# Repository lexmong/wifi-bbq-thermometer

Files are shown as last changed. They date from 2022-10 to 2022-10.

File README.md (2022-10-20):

# wifi-bbq-thermometer

An ESP8266 based wifi bbq thermometer using angularjs and bootstrap.
<br>
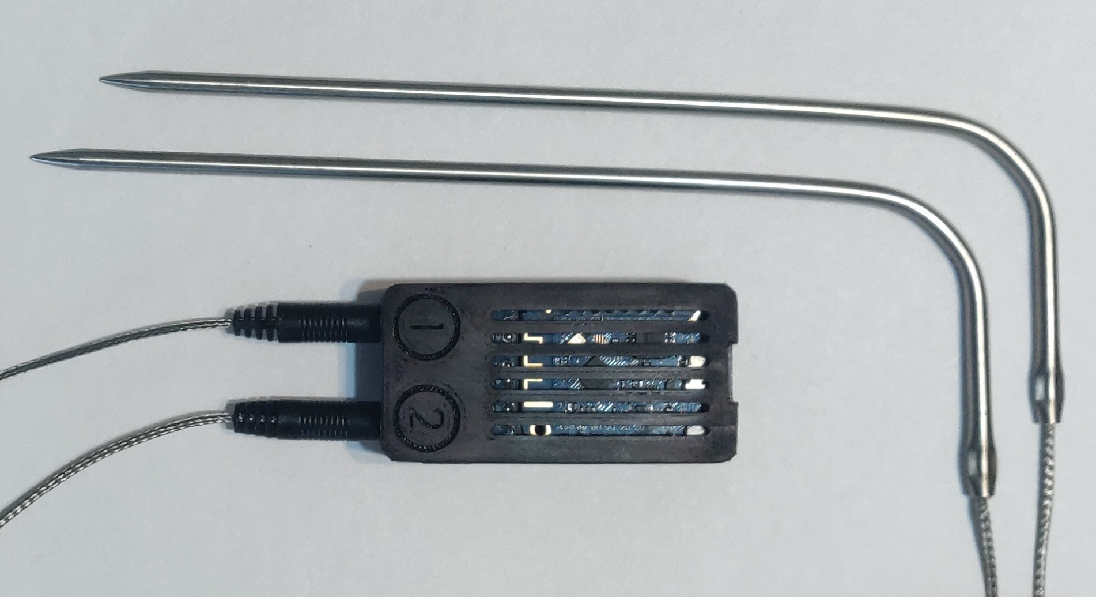
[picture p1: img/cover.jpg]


## Parts
|Qty|Part|Link|
|-|-|-|
|1|LOLIN D1 mini 3.1.0 |[Aliexpress](https://aliexpress.com/item/32831353752.html)|
|1|ADS1115 |[Aliexpress](https://aliexpress.com/item/32761481134.html)|
|2|2.5mm jack|[Aliexpress](https://aliexpress.com/item/32818269934.html)|
|2|Bbq probe (any should work)|[Aliexpress](https://aliexpress.com/item/1005001483369562.html)|
|6|4 pins female header|[Aliexpress](https://aliexpress.com/item/1005003610333849.html)|
|1|Male header (2x 8 pins + 1x 10 pins)|[Aliexpress](https://aliexpress.com/item/32623553746.html)|
|1|Perfboard (10x19 holes)||
|2|100kΩ resistor||

## Assembly
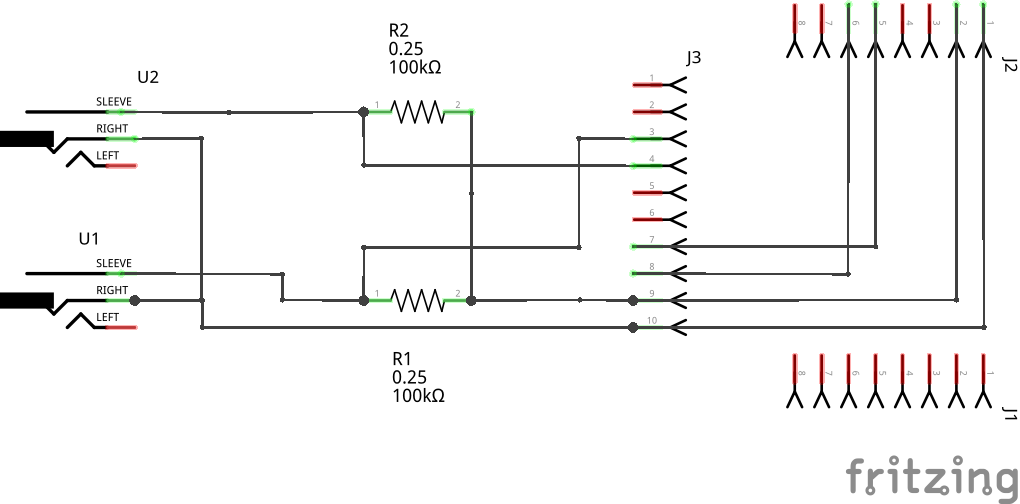
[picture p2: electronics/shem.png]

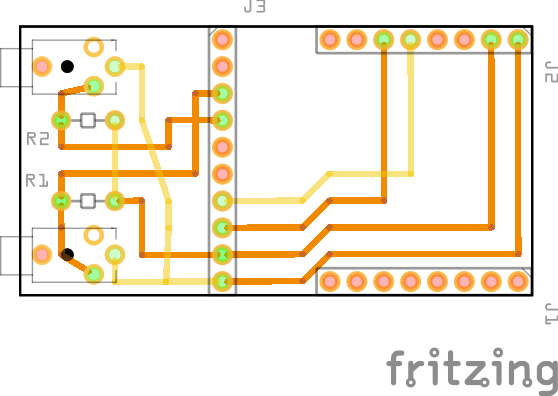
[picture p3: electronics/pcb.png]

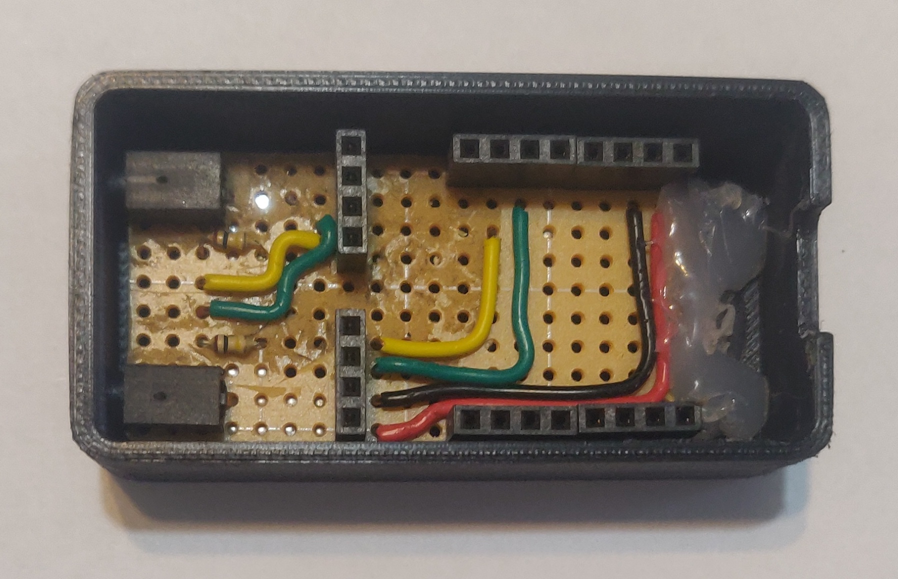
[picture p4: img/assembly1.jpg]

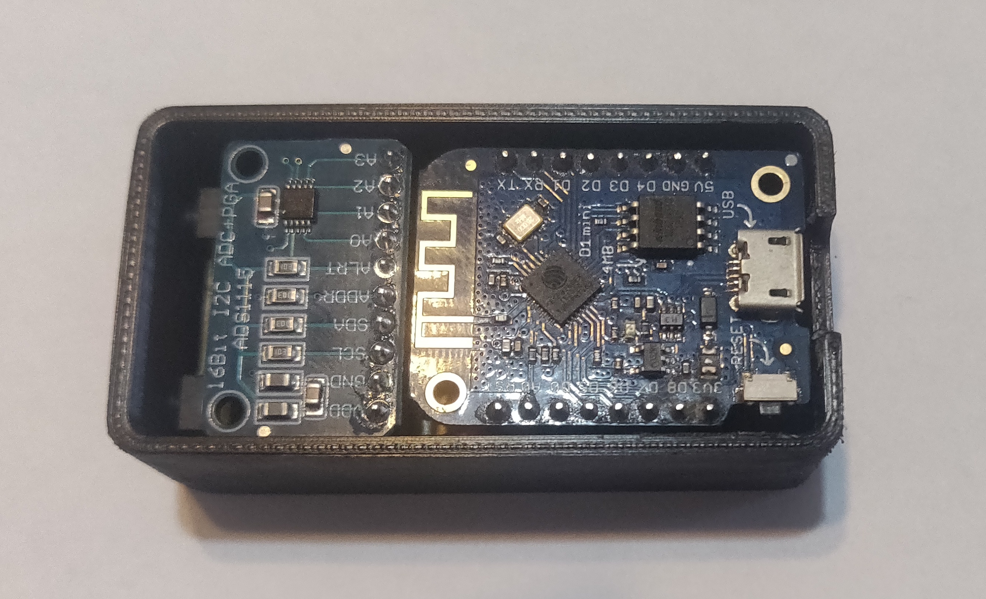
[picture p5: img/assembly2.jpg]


## Libraries
|Library|Link|
|-|-|
|ESP8266 Arduino Core|[Installation](https://arduino-esp8266.readthedocs.io/en/latest/installing.html)|
|Arduino ESP8266 filesystem uploader|[Installation](https://github.com/esp8266/arduino-esp8266fs-plugin)|
|ArduinoJson|[Installation](https://arduinojson.org/v6/doc/installation/)|
|Adafruit-ads1x15|[Installation](https://www.arduino.cc/reference/en/libraries/adafruit-ads1x15/)|

## Setup
1. Edit wifi_config_template.h
   - Set SSID, password, and hostname
   - Rename wifi_config_template.h to wifi_config.h
2. Upload sketch
3. Upload sketch data

## Probe calibration
Read the probe resistance at three different temperatures to calibrate. For best results, chose two temperatures close to the upper and lower bound of the operating range and one in the middle. Once submitted, the coefficients are calculated and saved to SPIFFS.



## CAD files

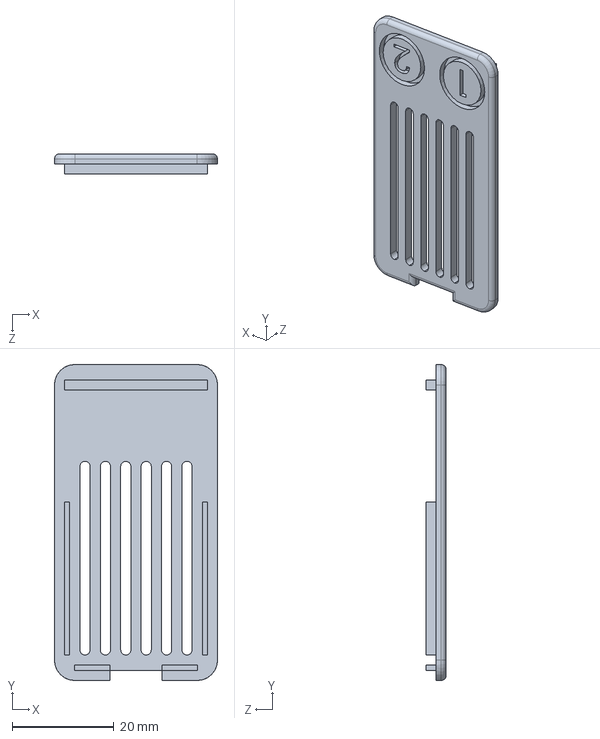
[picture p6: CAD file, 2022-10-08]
case/top.SLDPRT
32.0 x 62.0 x 4.00 mm

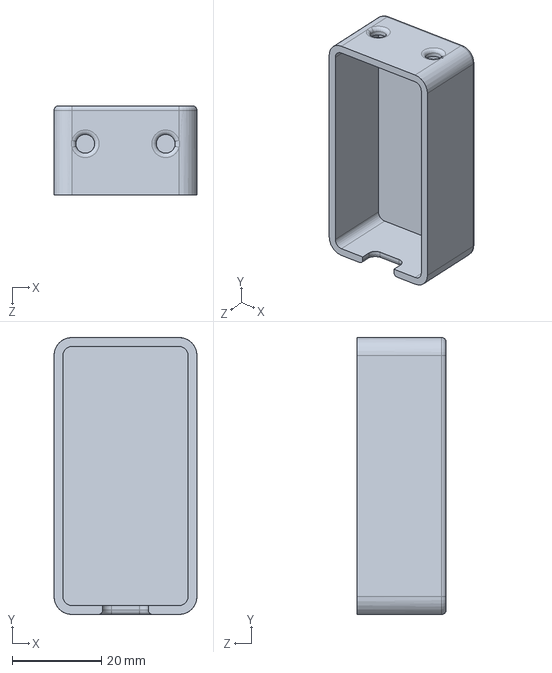
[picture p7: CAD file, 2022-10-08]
case/bottom.SLDPRT
32.0 x 62.0 x 20.0 mm

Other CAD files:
case/bottom.STL
case/top.STL

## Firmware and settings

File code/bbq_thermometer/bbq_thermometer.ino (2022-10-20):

#include <ArduinoJson.h>
#include <ESP8266WebServer.h>
#include <FS.h>
#include "wifi_config.h"
#include "utils.h"
#include "probe.h"
#include "network.h"

ESP8266WebServer server(80);
const int BUFFER_MAX = 1000;
char* PATH_COEFFICIENTS = "/coeffs.json";

void setup() {
  Serial.begin(115200);
  pinMode(LED_BUILTIN, OUTPUT);
  digitalWrite(LED_BUILTIN, LOW);
  
  initNetwork(WIFI_SSID,WIFI_PASSWORD,HOSTNAME);
  initAds();

  SPIFFS.begin();
  server.serveStatic("/", SPIFFS, "/index.html");
  server.serveStatic("/grill-outline.png", SPIFFS, "/grill-outline.png");
  server.serveStatic("/Poppins-Regular.ttf", SPIFFS, "/Poppins-Regular.ttf");
  server.serveStatic("/app.js", SPIFFS, "/app.js");
  server.serveStatic("/probes.html", SPIFFS, "/probes.html");
  server.serveStatic("/config.html", SPIFFS, "/config.html");
  server.serveStatic("/style.css", SPIFFS, "/style.css");

  if(loadCoefficients(PATH_COEFFICIENTS)){
    Serial.println("Coefficients loaded");
    for(int i =0; i< N_PROBES; i++){
      Serial.print("    probe ");
      Serial.println(i+1);
      for(int j=0;j<3;j++){
        Serial.print("        ");
        Serial.println(coeffs[i][j],10);
      }
    }
  }
  else Serial.println("Failed to load coefficents");

  server.onNotFound([](){
    server.send(404, "text/plain", "404: Not Found");
  });

  /**
   * Read temperature
   * GET args: unit ('c','f')
   */
  server.on("/readTemperature",[](){
    DynamicJsonDocument doc(BUFFER_MAX);
    char buf[BUFFER_MAX];
    double val;

    for(int i=0;i<N_PROBES;i++){
      val= getTemperature(getResistance(i),coeffs[i]);
      if(server.arg("unit") == "c") val = ktoc(val);
      else if(server.arg("unit") == "f") val = ktof(val);
      doc[i] = val;
    }
    
    serializeJson(doc, buf);
    server.send(200, "text/json", buf);
  });

  /**
   * Read resistance
   * GET args: probe (probe id 1 indexed)
   */
  server.on("/readResistance",[](){
    DynamicJsonDocument doc(BUFFER_MAX);
    char buf[BUFFER_MAX];
    int probe = server.arg("probe").toInt()-1;
    
    if(probe > -1 && probe < N_PROBES){
      doc[0] = getResistance(probe);
    }
    
    serializeJson(doc, buf);
    server.send(200, "text/json", buf);
  });

  /**
   * Calculates and returns coefficients 
   * GET args: 
   * points: JSON [{'temperature'=>t,'resistance'=>},{'temperature'=>t,'resistance'=>},...] 
   * probe: (probe id 1 indexed)
   * unit: c,f
   */
  server.on("/saveCoeffs",[](){
    DynamicJsonDocument doc(BUFFER_MAX);
    char buf[BUFFER_MAX];
    int probe;

    deserializeJson(doc,server.arg("points"));
    probe = server.arg("probe").toInt()-1;

    //fahrenheit
    if(server.arg("unit").charAt(0) == 102){
      doc[0]["temperature"] = ftoc(doc[0]["temperature"].as<double>());
      doc[1]["temperature"] = ftoc(doc[1]["temperature"].as<double>());
      doc[2]["temperature"] = ftoc(doc[2]["temperature"].as<double>());
    }

    
    getCoefficients(
      ctok(doc[0]["temperature"].as<double>()),
      ctok(doc[1]["temperature"].as<double>()),
      ctok(doc[2]["temperature"].as<double>()),
      doc[0]["resistance"].as<double>(),
      doc[1]["resistance"].as<double>(),
      doc[2]["resistance"].as<double>(),
      coeffs[probe]
    );

    doc.clear();

    doc["a"] = coeffs[probe][0];
    doc["b"] = coeffs[probe][1];
    doc["c"] = coeffs[probe][2];

    saveCoefficients(PATH_COEFFICIENTS);

    serializeJson(doc, buf);

    server.send(200, "text/json", buf);
  });

  server.begin();
  Serial.println("HTTP server started");
  digitalWrite(LED_BUILTIN, HIGH);
}

void loop() {
  MDNS.update();
  server.handleClient();
}

/***
 * Load coefficients from JSON file
 */
bool loadCoefficients(char* path) {
  StaticJsonDocument<1024> doc;
  File f;
  
  f = SPIFFS.open(path, "r");
  if(!f)return false;

 
  if(deserializeJson(doc, f)){
    f.close();
    return false;
  }

  for(int i =0; i< N_PROBES; i++){
    coeffs[i][0] = doc[i]["a"].as<double>();
    coeffs[i][1] = doc[i]["b"].as<double>();
    coeffs[i][2] = doc[i]["c"].as<double>();
  }

  f.close();
  return true;
}

/**
 * Save coefficients to JSON file
 */

bool saveCoefficients(char* path) {
  DynamicJsonDocument doc(BUFFER_MAX);
  File f;
  
  f = SPIFFS.open(path, "w");
  if(!f)return false;

  for(int i =0;i<N_PROBES;i++){
    doc[i]["a"] = coeffs[i][0];
    doc[i]["b"] = coeffs[i][1];
    doc[i]["c"] = coeffs[i][2];
  }

  serializeJson(doc,f);
  f.close();
  return false;
}

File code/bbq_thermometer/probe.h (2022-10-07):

#include <math.h>
#include <Adafruit_ADS1X15.h>

const int N_PROBES = 2;

Adafruit_ADS1115 ads;
double vRef = 4.52;
double rRef = 100000;
double coeffs[N_PROBES][3];

void initAds(){
  if (!ads.begin()) {
    Serial.println("Failed to initialize ADS.");
    while(1);
  }
  ads.setDataRate(7); 
  Serial.println("ADS initialized");
}

/**
 * Read resistance from adc
 * pin: input on the adc
 */
double getResistance(int pin){
  int16_t adc = ads.readADC_SingleEnded(pin);
  double volts= ads.computeVolts(adc);
  return volts > 0? rRef * (vRef/volts) - rRef:-1;
}

/**
 * Get temperature from resistance and Steinhart–Hart coefficients
 * res: resistance in ohm
 * coeffs: coefficients double[3]
 */
double getTemperature(double res,double* coeffs){
  if(res<0) return -1;
  double temp = log(res);
  temp = 1 / (coeffs[0] + (coeffs[1] * temp) + (coeffs[2] * temp * temp * temp));

  return temp;
}

/**
 * Get coefficients of Steinhart–Hart from 3 points  
 * k1,k2,k3: temperature in Kelvin
 * r1,r2,r3: resistance in ohm
 * 
 * https://en.wikipedia.org/wiki/Steinhart%E2%80%93Hart_equation
 */ 
void getCoefficients(double k1,double k2,double k3,double r1,double r2,double r3,double* coeffs){
    if(r1 == 0 || r2 ==0 || r3 == 0) return;
    if (r1 == r2 || r1 == r3 || r2 == r3) return;
    
    double l1 = log(r1),l2 = log(r2),l3 = log(r3);
    if(l1+l2+l3 == 0) return;
    
    double y1 = 1/k1, y2 = 1/k2,y3 = 1/k3;
    double g2 = (y2-y1)/(l2-l1),g3 = (y3-y1)/(l3-l1);
    
    coeffs[2] = (g3-g2)/(l3-l2)*(1/(l1+l2+l3));
    coeffs[1] = g2-coeffs[2] *(l1*l1+l1*l2+l2*l2);
    coeffs[0] = y1 - ((coeffs[1]+l1*l1*coeffs[2])*l1);
}

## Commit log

2022-10-06 Added probe configuration page + coefficients loading via json
2022-10-08 Added electronics + 3d files
    [bottom.SLDPRT, bottom.STL, top.SLDPRT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]
2022-10-20 Added probe calibration
